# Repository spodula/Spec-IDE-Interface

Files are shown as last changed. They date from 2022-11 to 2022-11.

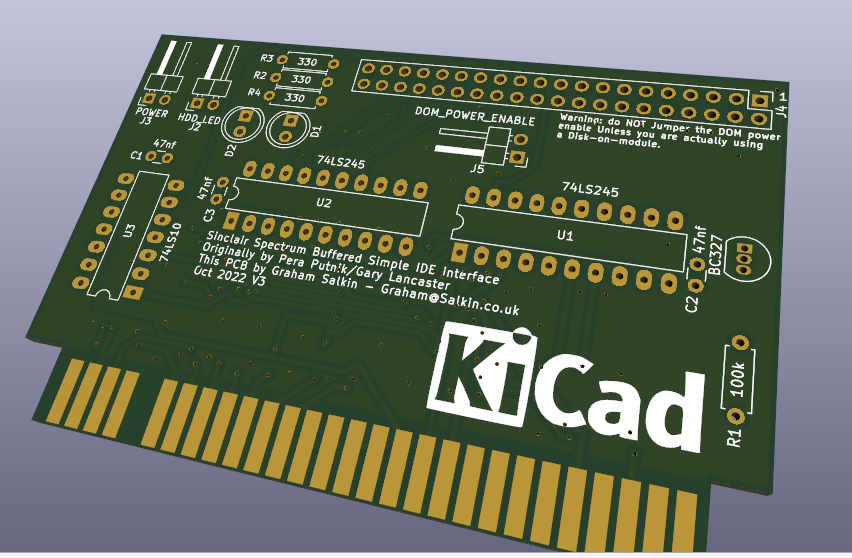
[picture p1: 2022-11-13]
Buffered/buffered.png

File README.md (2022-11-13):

# Spec-IDE-Interface
Buffered and Unbuffered 8 bit IDE interfaces for the zx Spectrum.

This is a (Another) remake of the Pera Putnik/Gary Lancaster design for a simple 8-bit IDE interface for the zx Spectrum.

There are two versions of this, and unbuffered version which is basically the same as the PP/GL design except with additional HDD and Power LED pins.

The Buffered one buffers all the lines going to the Hard drive, which should make the interface more reliable for longer cable lengths.

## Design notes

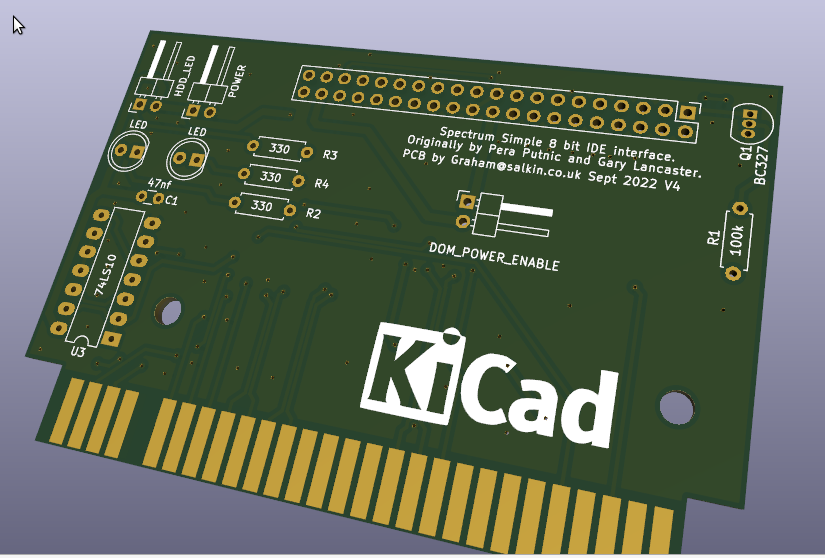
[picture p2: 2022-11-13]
Unbuffered/unbuffered.png

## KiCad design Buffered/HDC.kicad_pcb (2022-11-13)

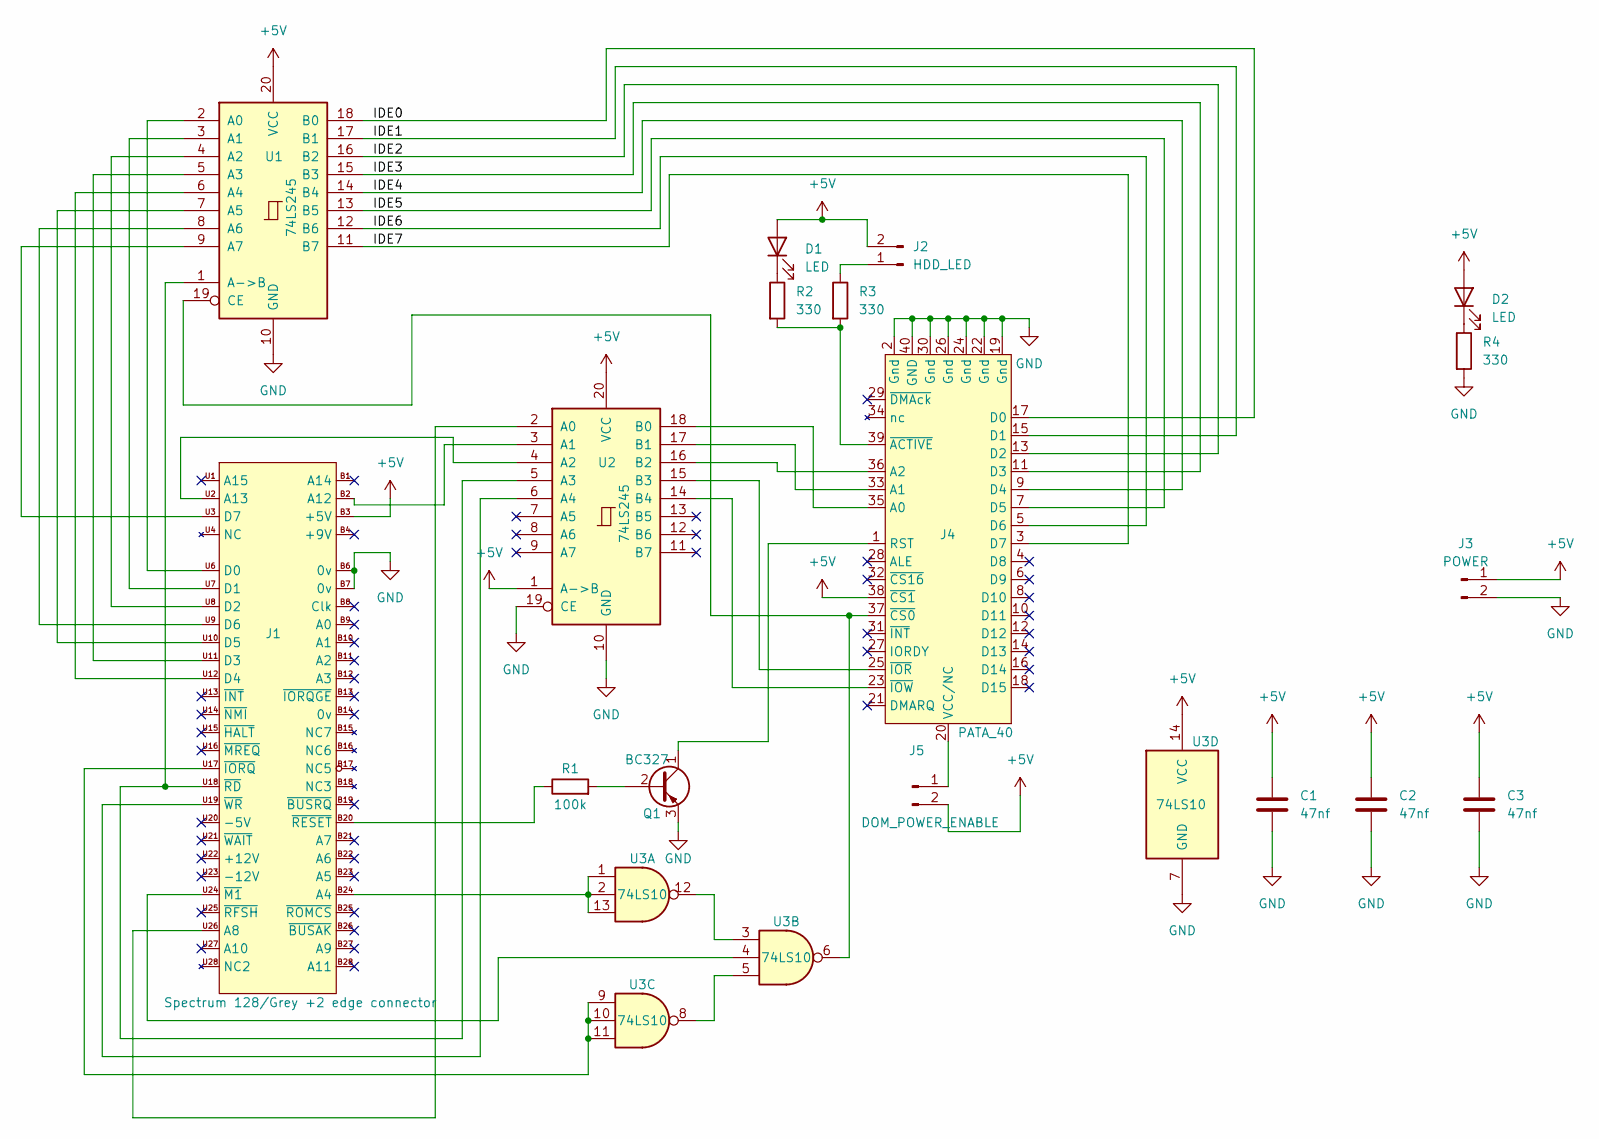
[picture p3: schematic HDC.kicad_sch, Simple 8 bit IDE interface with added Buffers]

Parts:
C1, C2, C3: 47nf; C_Disc_D3.0mm_W1.6mm_P2.50mm
D1, D2: LED; LED_D5.0mm
J1: Spectrum 128/Grey +2 edge connector; Speccy_edge_External
J2: HDD_LED; PinHeader_1x02_P2.54mm_Horizontal
J3: POWER; PinHeader_1x02_P2.54mm_Horizontal
J4: PATA_40; PinHeader_2x20_P2.54mm_Vertical
J5: DOM_POWER_ENABLE; PinHeader_1x02_P2.54mm_Horizontal
Q1: BC327; TO-92_Inline
R1: 100k; R_Axial_DIN0207_L6.3mm_D2.5mm_P7.62mm_Horizontal
R2, R3, R4: 330; R_Axial_DIN0207_L6.3mm_D2.5mm_P7.62mm_Horizontal
U1, U2: 74LS245; DIP-20_W7.62mm_LongPads
U3: 74LS10; DIP-14_W7.62mm_LongPads

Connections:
+5V: C1.1, C2.1, C3.1, D1.2 (A), D2.2 (A), J1.B3 (+5V), J2.2, J3.1, J4.38 (~CS1), J5.2, U1.20 (VCC), U2.1 (A->B), U2.20 (VCC), U3.14 (VCC)
/IDE0: J4.17 (D0), U1.18 (B0)
/IDE1: J4.15 (D1), U1.17 (B1)
/IDE2: J4.13 (D2), U1.16 (B2)
/IDE3: J4.11 (D3), U1.15 (B3)
/IDE4: J4.9 (D4), U1.14 (B4)
/IDE5: J4.7 (D5), U1.13 (B5)
/IDE6: J4.5 (D6), U1.12 (B6)
/IDE7: J4.3 (D7), U1.11 (B7)
GND: C1.2, C2.2, C3.2, J1.B6 (0v), J1.B7 (0v), J3.2, J4.2 (Gnd), J4.19 (Gnd), J4.22 (Gnd), J4.24 (Gnd), J4.26 (Gnd), J4.30 (Gnd), J4.40 (GND), Q1.3 (E), R4.2, U1.10 (GND), U2.10 (GND), U2.19 (CE), U3.7 (GND)
unnamed: D1.1 (K), R2.1
unnamed: D2.1 (K), R4.1
unnamed: J1.B2 (A12), U2.3 (A1)
unnamed: J1.B20 (~RESET), R1.1
unnamed: J1.B24 (A4), U3.1, U3.2, U3.13
unnamed: J1.U2 (A13), U2.4 (A2)
unnamed: J1.U3 (D7), U1.9 (A7)
unnamed: J1.U6 (D0), U1.2 (A0)
unnamed: J1.U7 (D1), U1.3 (A1)
unnamed: J1.U8 (D2), U1.4 (A2)
unnamed: J1.U9 (D6), U1.8 (A6)
unnamed: J1.U10 (D5), U1.7 (A5)
unnamed: J1.U11 (D3), U1.5 (A3)
unnamed: J1.U12 (D4), U1.6 (A4)
unnamed: J1.U17 (~IORQ), U3.9, U3.10, U3.11
unnamed: J1.U18 (~RD), U1.1 (A->B), U2.5 (A3)
unnamed: J1.U19 (~WR), U2.6 (A4)
unnamed: J1.U24 (~M1), U3.4
unnamed: J1.U26 (A8), U2.2 (A0)
unnamed: J2.1, R3.1
unnamed: J4.1 (RST), Q1.1 (C)
unnamed: J4.20 (VCC/NC), J5.1
unnamed: J4.23 (~IOW), U2.14 (B4)
unnamed: J4.25 (~IOR), U2.15 (B3)
unnamed: J4.33 (A1), U2.17 (B1)
unnamed: J4.35 (A0), U2.18 (B0)
unnamed: J4.36 (A2), U2.16 (B2)
unnamed: J4.37 (~CS0), U1.19 (CE), U3.6
unnamed: J4.39 (~ACTIVE), R2.2, R3.2
unnamed: Q1.2 (B), R1.2
unnamed: U3.5, U3.8
unnamed: U3.3, U3.12

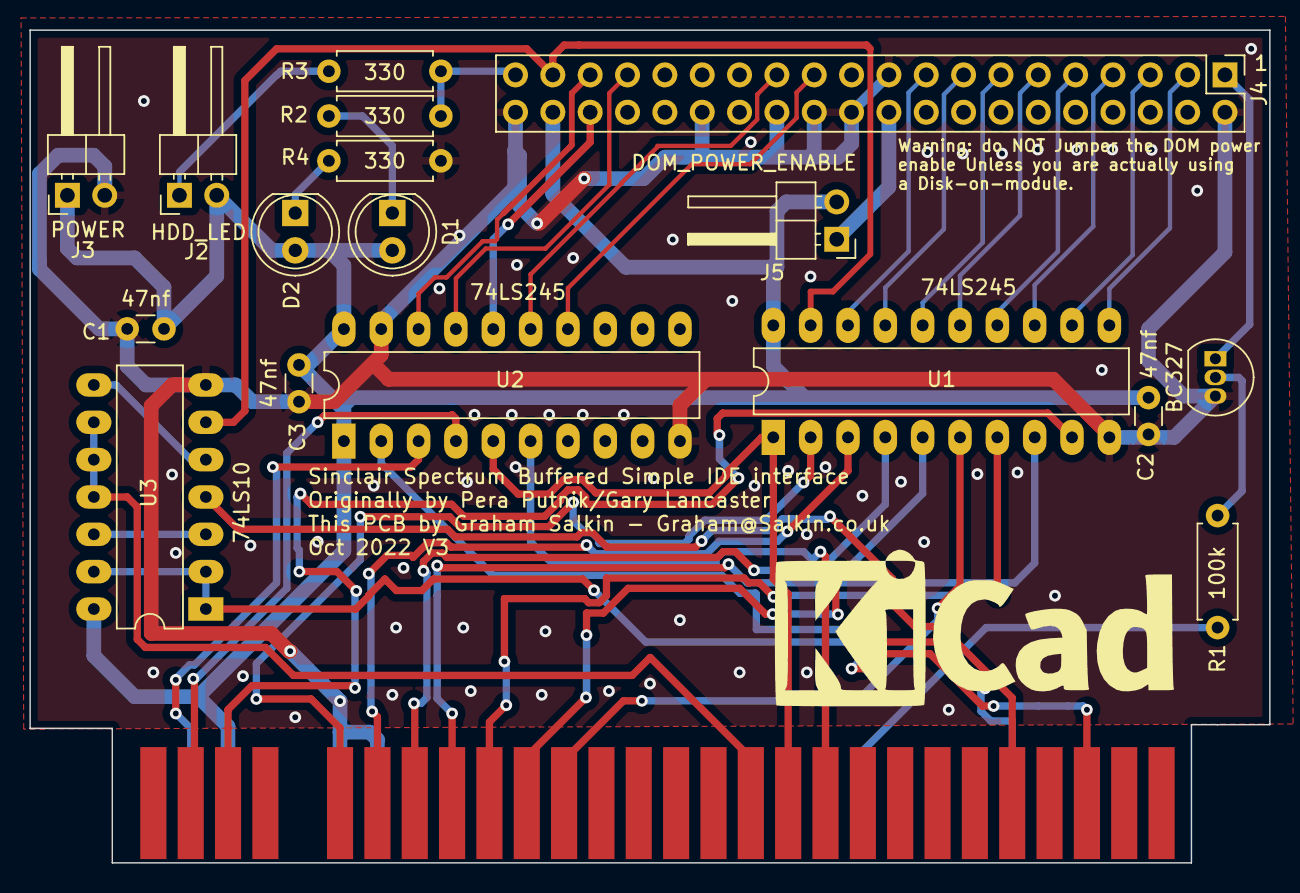
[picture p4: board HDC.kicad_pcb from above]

Board: 2 copper layers, 84.3 x 56.6 mm, 18 parts (0 on the bottom side), 42 nets.

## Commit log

2022-11-13 Initial login
    [HDC-B_Cu.gbr, HDC-B_Mask.gbr, HDC-B_Paste.gbr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]
2022-11-13 Fixed the silk screen on the buffered version to properly credit the original designers.
    [HDC-B_Cu.gbr, HDC-B_Mask.gbr, HDC-B_Paste.gbr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]
